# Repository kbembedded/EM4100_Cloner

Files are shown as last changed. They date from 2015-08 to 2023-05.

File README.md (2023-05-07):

EM4100 Cloner
=================

This RFID project is the second iteration of the RFID board for DEF CON's DarkNet game.  This project is based on the OPEN RFID tag with resources pulled from t4f.org and kukata86.com.  Envelope detector credit to multiple people listed here: http://playground.arduino.cc/Main/DIYRFIDReader

This project is to create a battery powered RFID cloner that is compatible with LF 125kHz RFID tags, a.k.a. EM4100.  There are 16 slots each able to store a 5 ID.  This device does not clone a tag and reprogram another, it is able to read and clone a tag and then turn around to emulate it to a proper transponder.  There is also a mechanism to manually program an ID to the device via the button and DIP switch.  Any of the 16 slots can have a cloned ID saved, a manually input ID saved, and an ID replayed from.

2023-05-06: I've discovered that Microchip has radically changed their assembler system. This will not compile under current MPLAB X IDEs, but should work on the older v3.50 or v3.55 (I think is what was originally used). They can still be found here: [https://www.microchip.com/en-us/tools-resources/archives/mplab-ecosystem#MPLAB%20XC%20Compiler%20Archives](https://www.microchip.com/en-us/tools-resources/archives/mplab-ecosystem#MPLAB%20XC%20Compiler%20Archives) If that link ever goes stale, well, good luck.

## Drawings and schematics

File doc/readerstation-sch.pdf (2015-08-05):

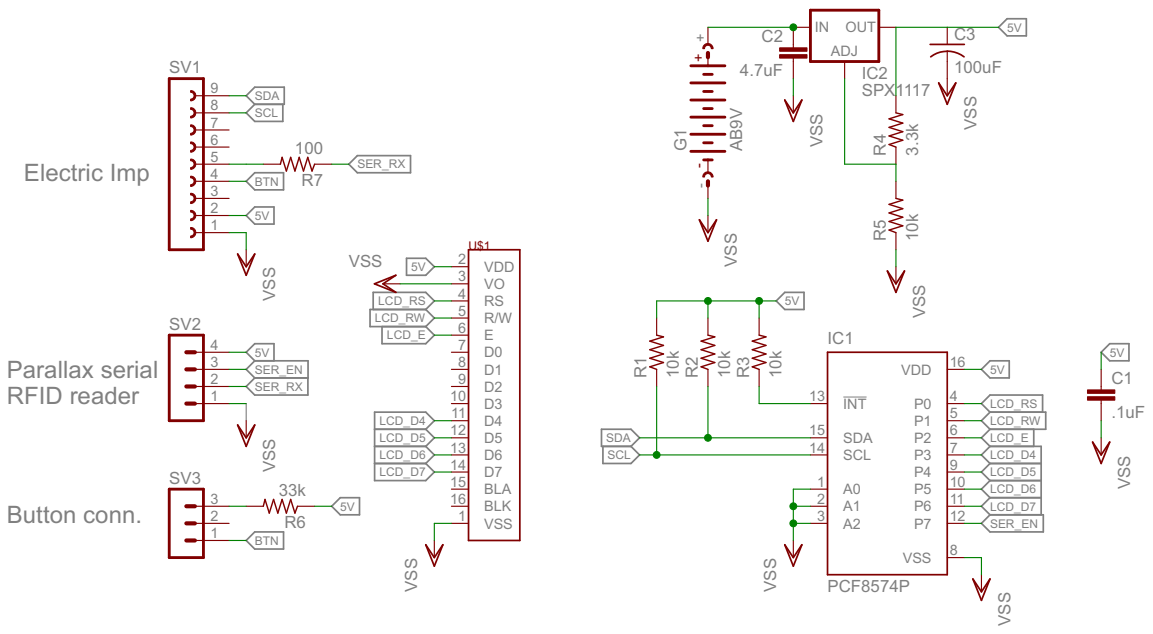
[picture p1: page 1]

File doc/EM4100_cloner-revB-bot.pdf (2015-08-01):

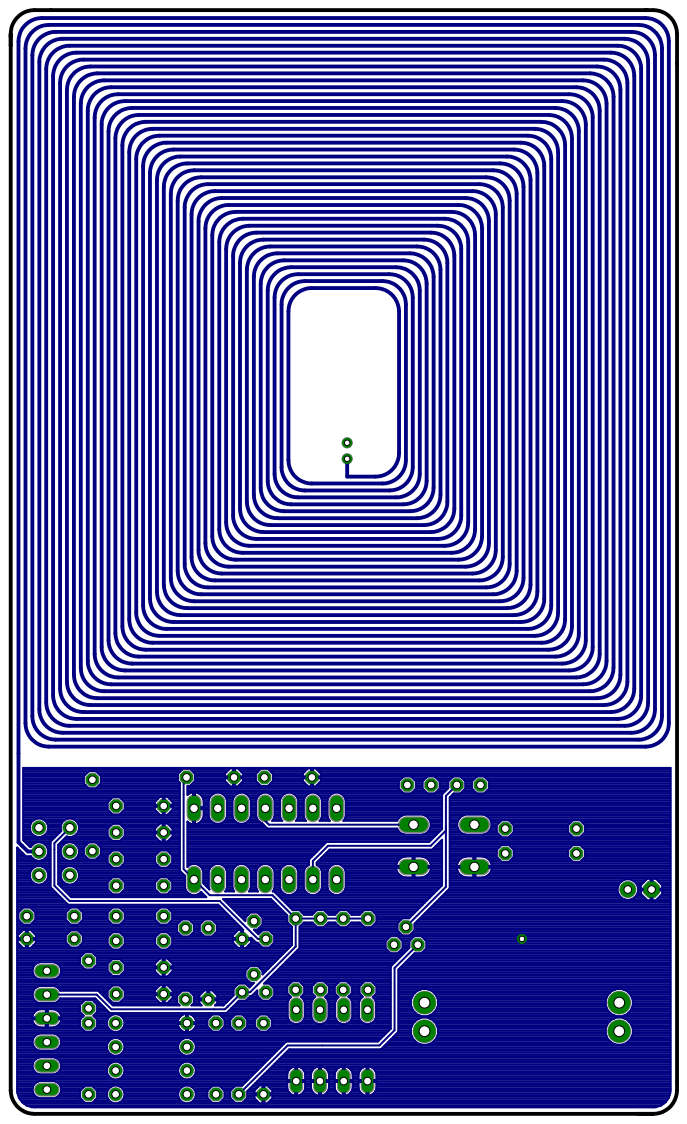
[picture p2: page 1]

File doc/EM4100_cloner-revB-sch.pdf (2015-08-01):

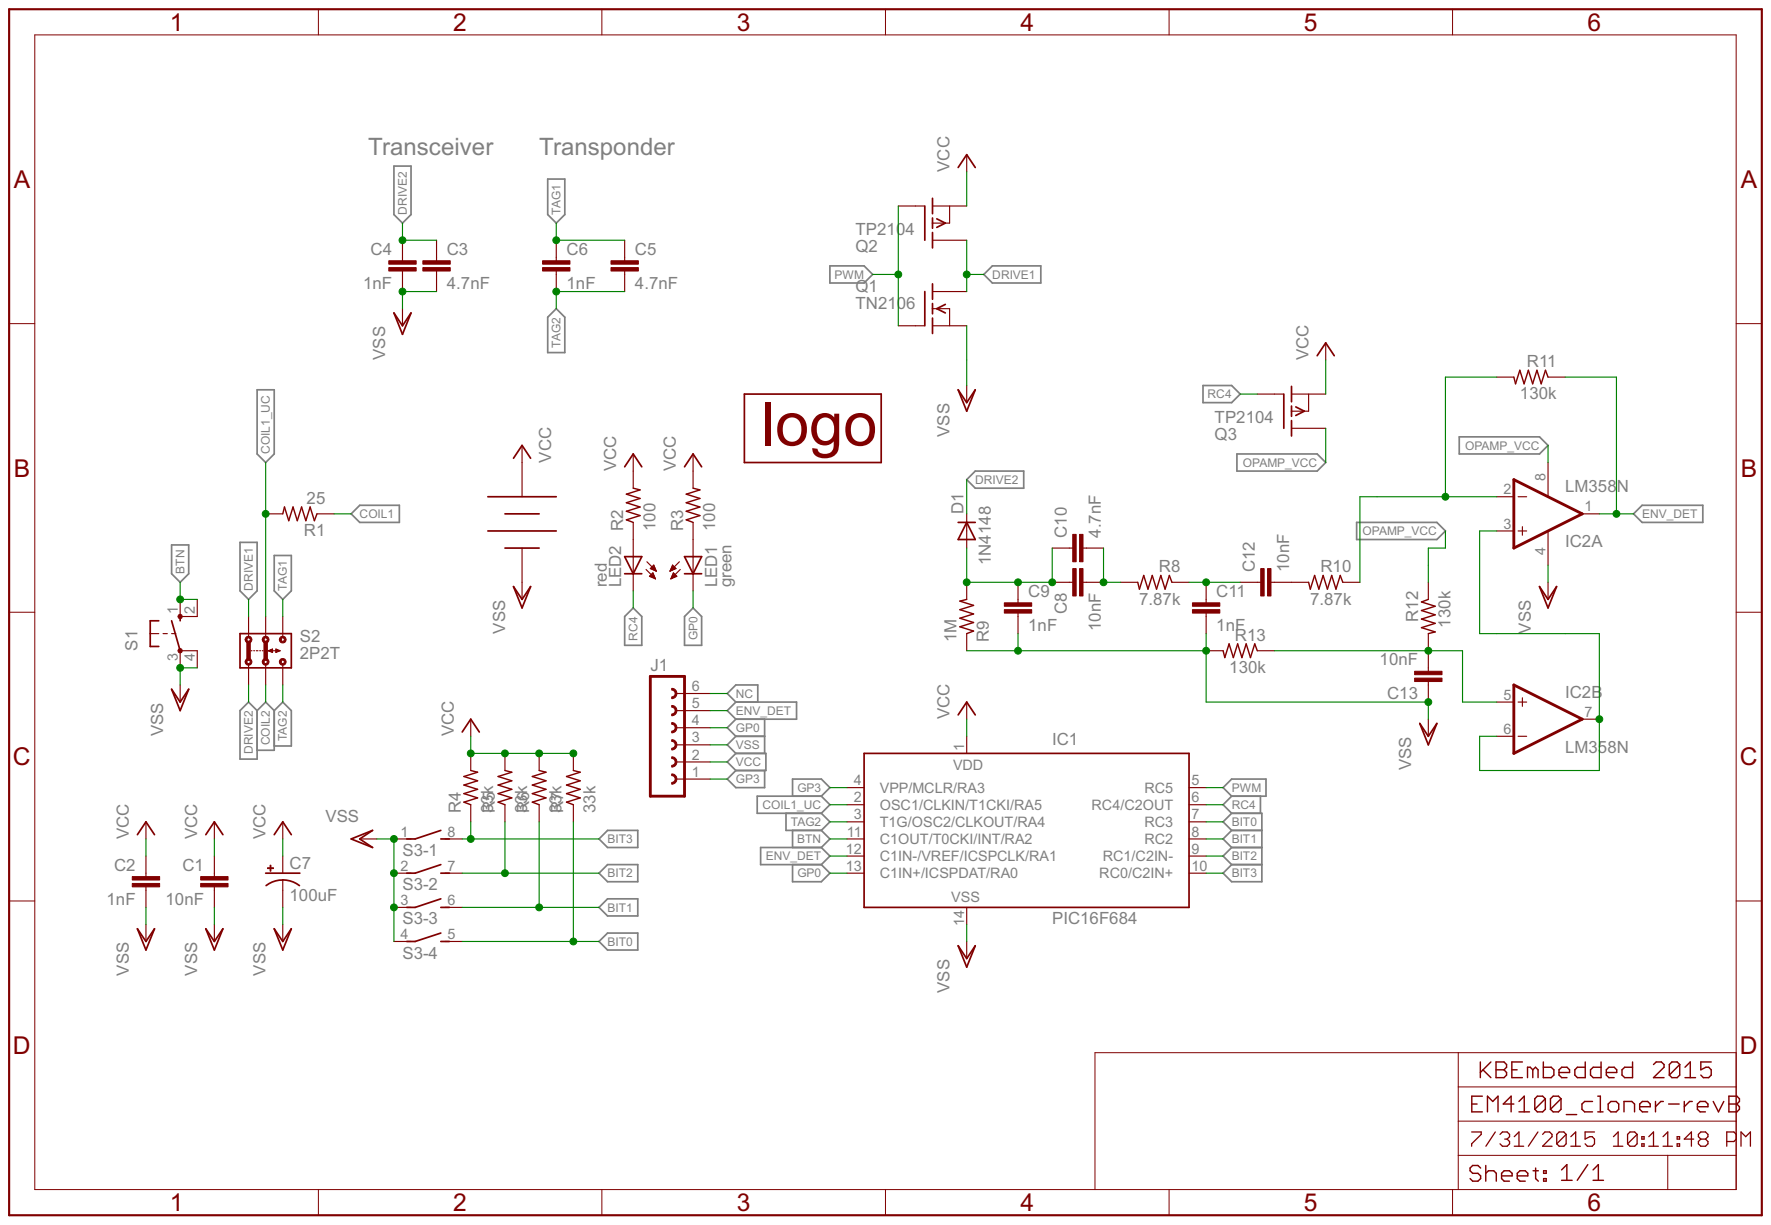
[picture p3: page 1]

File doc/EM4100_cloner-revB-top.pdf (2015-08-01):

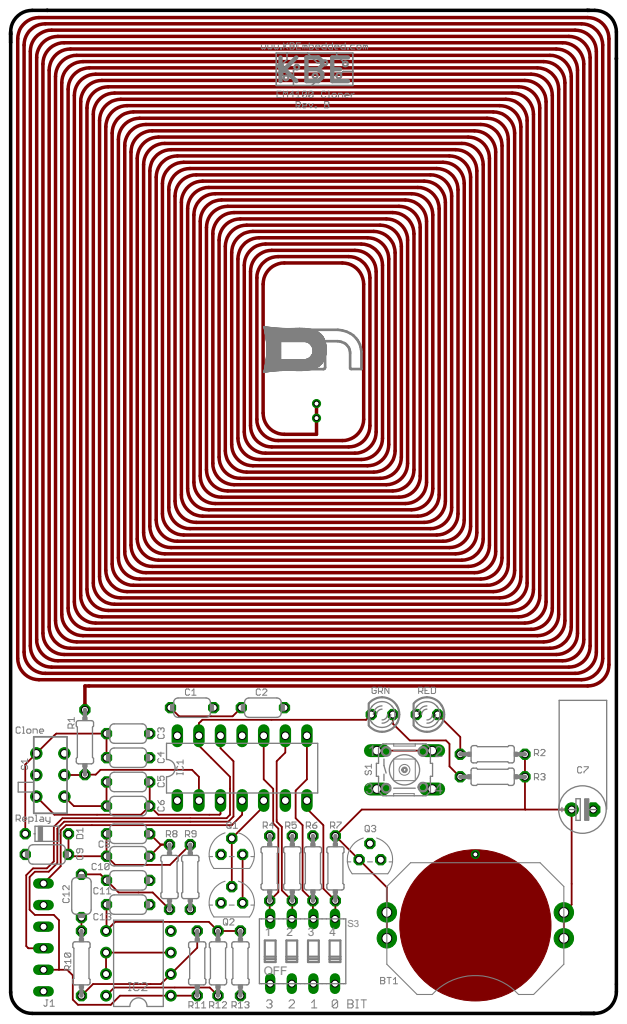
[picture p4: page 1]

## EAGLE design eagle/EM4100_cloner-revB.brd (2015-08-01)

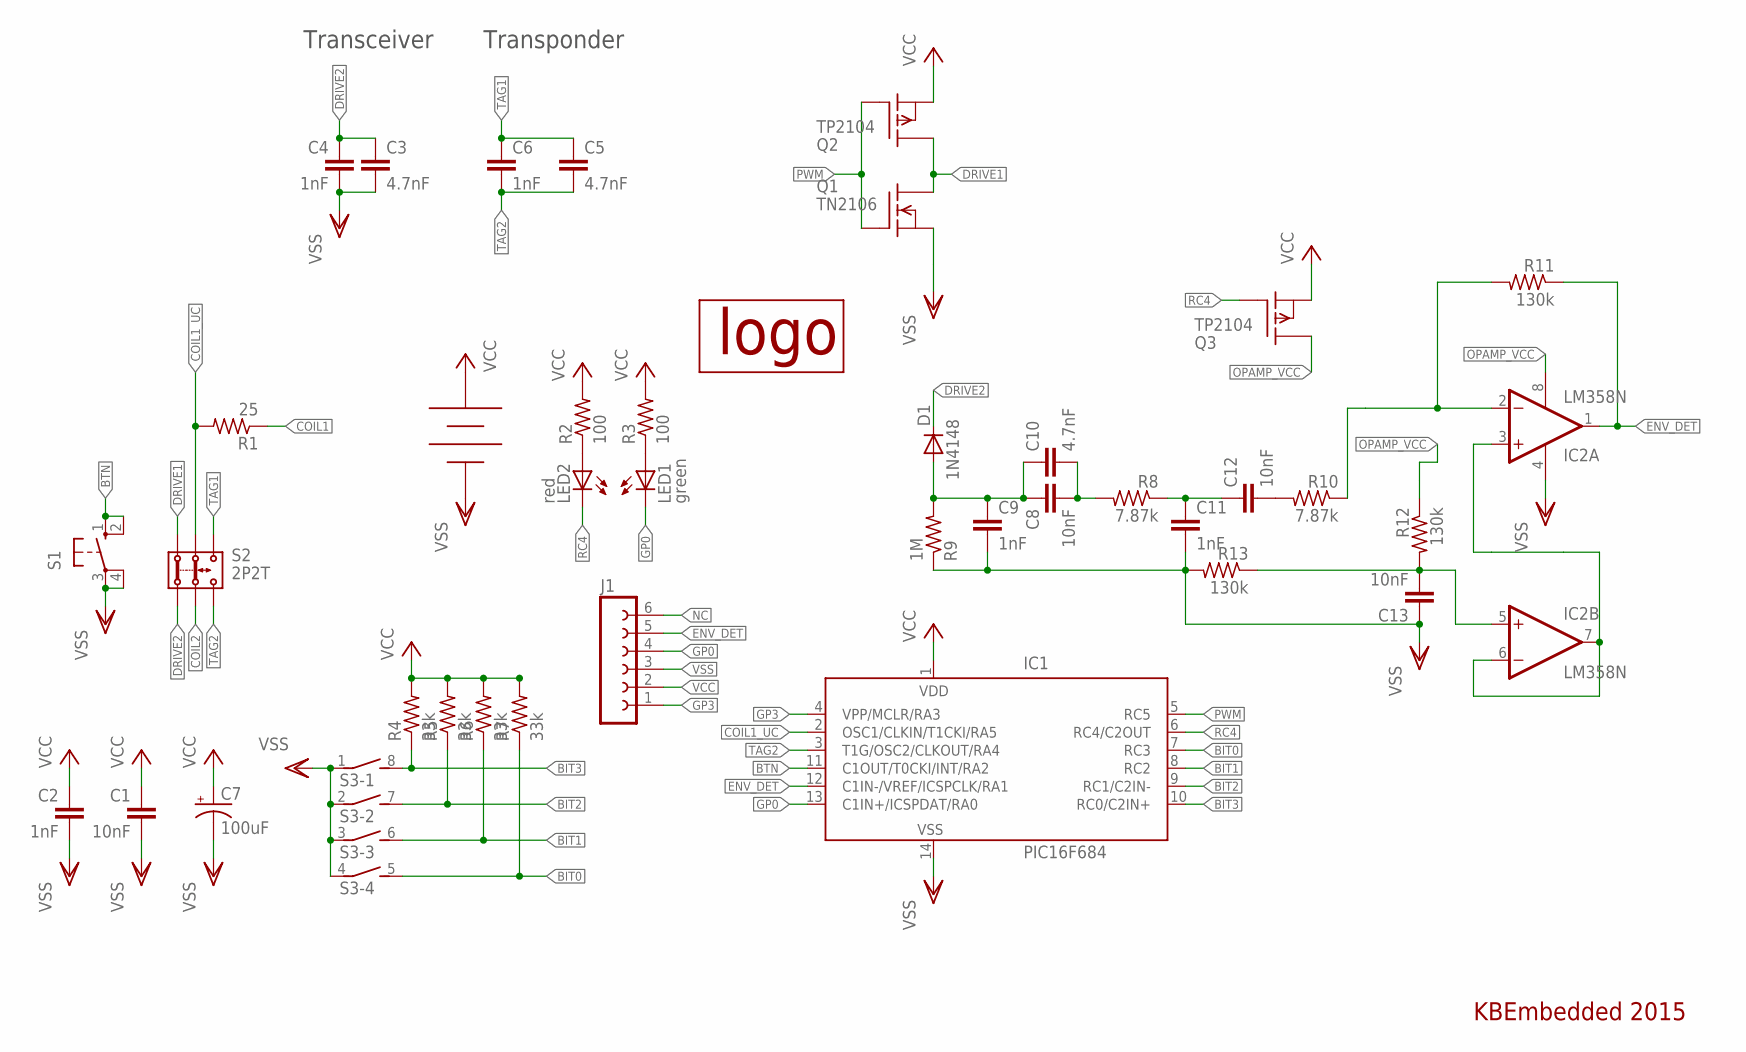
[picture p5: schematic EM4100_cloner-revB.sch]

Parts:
BT1: BAT-HLD-001-THM
C1, C8, C12, C13: 10nF; C050-024X044
C2, C4, C6, C9, C11: 1nF; C050-024X044
C3, C5, C10: 4.7nF; C050-024X044
C7: 100uF; E2,5-6E
D1: 1N4148; D-5
IC1: PIC16F684; DIL14
IC2: LM358N; DIL08
J1: FE06-1; FE06
LED1: green; LED3MM
LED2: red; LED3MM
Q1: TN2106; TO-92
Q2, Q3: TP2104; TO-92
R1: 25; 0204/7
R2, R3: 100; 0204/7
R4, R5, R6, R7: 33k; 0204/7
R8, R10: 7.87k; 0204/7
R9: 1M; 0204/7
R11, R12, R13: 130k; 0204/7
S1: 10-XX; B3F-10XX
S2: 2P2T
S3: DIP04S
U$1: KBELOGO-SILK

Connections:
BIT0: IC1.7 (RC3), R7.1, S3.5 (2)
BIT1: IC1.8 (RC2), R6.1, S3.6 (2)
BIT2: IC1.9 (RC1/C2IN-), R5.1, S3.7 (2)
BIT3: IC1.10 (RC0/C2IN+), R4.1, S3.8 (2)
BTN: IC1.11 (C1OUT/T0CKI/INT/RA2), S1.1 (S), S1.2 (S1)
COIL1: R1.1
COIL1_UC: IC1.2 (OSC1/CLKIN/T1CKI/RA5), R1.2, S2.2.1
COIL2: S2.2.2
DRIVE1: Q1.3 (D), Q2.3 (D), S2.1.1
DRIVE2: C3.1, C4.1, D1.C, S2.1.2
ENV_DET: IC1.12 (C1IN-/VREF/ICSPCLK/RA1), IC2.1 (OUT), J1.5, R11.1
GP0: IC1.13 (C1IN+/ICSPDAT/RA0), J1.4, LED1.K (C)
GP3: IC1.4 (VPP/MCLR/RA3), J1.1
unnamed: LED2.A, R2.1
unnamed: LED1.A, R3.1
unnamed: C8.1, C9.1, C10.1, D1.A, R9.2
unnamed: C8.2, C10.2, R8.2
unnamed: C11.1, C12.1, R8.1
unnamed: C12.2, R10.2
unnamed: IC2.3 (+IN), IC2.6 (-IN), IC2.7 (OUT)
unnamed: C13.2, IC2.5 (+IN), R12.2, R13.1
unnamed: IC2.2 (-IN), R10.1, R11.2
NC: J1.6
OPAMP_VCC: IC2.8 (V+), Q3.3 (D), R12.1
PWM: IC1.5 (RC5), Q1.2 (G), Q2.2 (G)
RC4: IC1.6 (RC4/C2OUT), LED2.K (C), Q3.2 (G)
TAG1: C5.1, C6.1, S2.3.1
TAG2: C5.2, C6.2, IC1.3 (T1G/OSC2/CLKOUT/RA4), S2.3.2
VCC: BT1.+@0 (VCC), BT1.+@1 (VCC), BT1.+@2 (VCC), BT1.+@3 (VCC), C1.1, C2.1, C7.+, IC1.1 (VDD), J1.2, Q2.1 (S), Q3.1 (S), R2.2, R3.2, R4.2, R5.2, R6.2, R7.2
VSS: BT1.- (VSS), C1.2, C2.2, C3.2, C4.2, C7.-, C9.2, C11.2, C13.1, IC1.14 (VSS), IC2.4 (V-), J1.3, Q1.1 (S), R9.1, R13.2, S1.3, S1.4 (P1), S3.1, S3.2 (1), S3.3 (1), S3.4 (1)

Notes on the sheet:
Transceiver
Transponder
KBEmbedded 2015

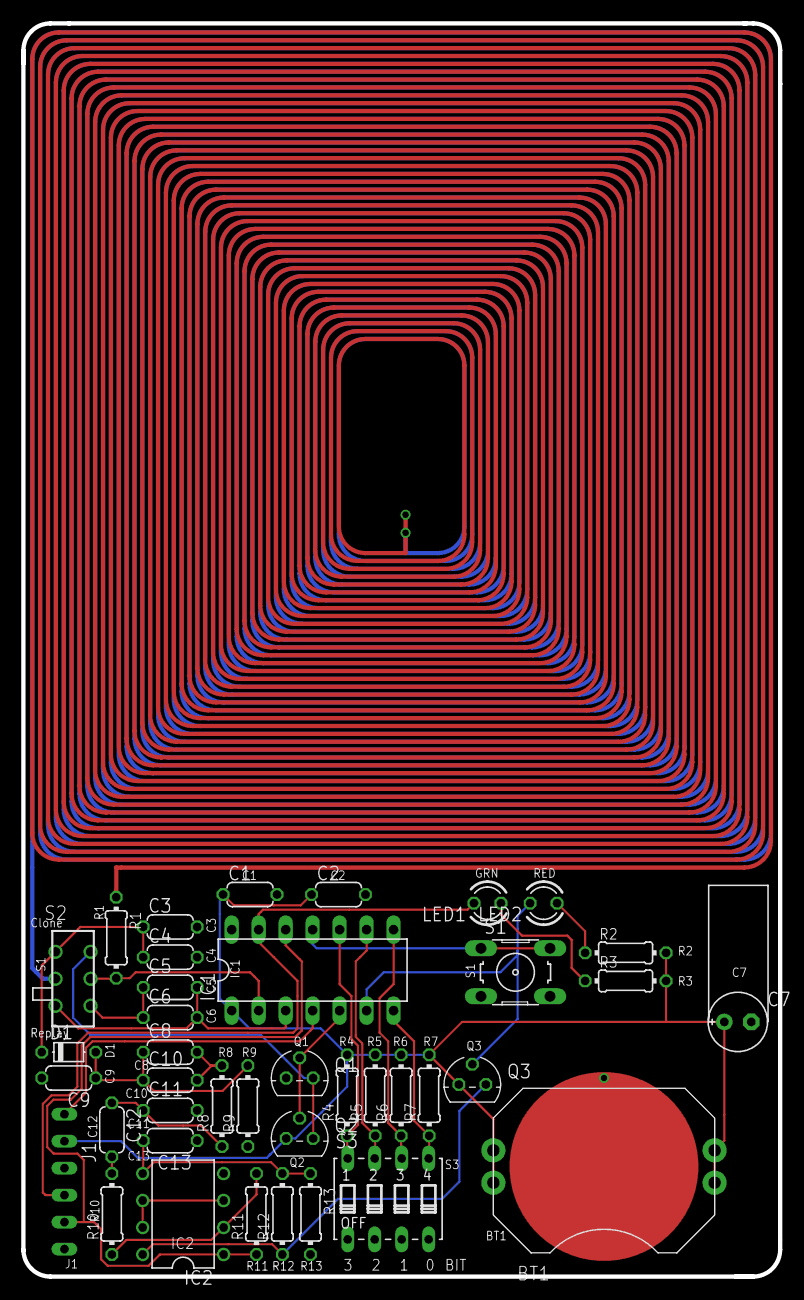
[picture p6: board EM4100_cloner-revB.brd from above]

Board: 2 copper layers, 71.2 x 118.0 mm, 41 parts (0 on the bottom side), 27 nets.

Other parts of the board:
U$2: DN_LOGO

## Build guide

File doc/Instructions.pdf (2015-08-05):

# EM4100 RFID Cloner Kit

This kit contains everything needed to build a low-frequency (125 kHz) EM4100 compatible device capable of cloning and replaying RFID tags. All of the documentation, hardware, and software is available on github: https://github.com/kbembedded/EM4100_Cloner
The whole device is controlled by a PIC16F684 microcontroller, which is pre-programmed. The software currently supports cloning of read-only LF RFID tags, a manual input of arbitrary IDs, and replaying the stored IDs to standard RFID transceivers. There are a total of 16 locations available to save IDs to or replay from.
If you have any issues, are missing parts, or just have questions, ask in the Hardware Hacking Village at DEF CON, or send an email to support@kbembedded.com

See the schematic and layout PDFs, located in the doc/
directory for more information about the circuit
Label | Description | Notes about assembly:
R1 | 25 Ohm | IC1, IC2, S2, S3, C7, D1, GRN, RED, BT1 and Q1-Q3
R2, R3 | 100 Ohm | IC1 and IC2 have notches on the chip and the PCB that should match up
R4, R5, R6, R7 | 33 kOhm | S2 has the slider tab marked on the PCB to note orientation.
R8, R10 | 7.87 kOhm | S3 has a white dot on the upper-right corner and lines up with “S3”
R9 | 1M Ohm | C7 has a white stripe on the negative (cathode) side of the capacitor. The
R11, R12, R13 | 130 kOhm | capacitor must be mounted with the stripe opposite the “+” symbol.
IC1 | PIC16F684 | D1 must have the stripe on the component match the stripe on the PCB
IC2 | LM258/LM358 | GRN & RED both have one leg shorter than the other; the shorter leg is the
S2 | Slide Switch (mislabeled on PCB) | negative (cathode) leg and needs to line up with the flat side printed on
D1 | 1N4148 Signal Diode | the PCB.
C2, C4, C6, C9, C11 | 1 nF Ceramic | BT1 must be mounted with the concave circle closest to the edge of the
C3, C5, C10 | 4.7 nF Ceramic | PCB.
C1, C8, C12, C13 | 10 nF Ceramic | Q1-Q3 must be mounted facing the same was as the silkscreen on the PCB
C7 | 100 uF Aluminum, lay flat | J1 is optional and can be used to reprogram the PIC
BT1 | CR2032 Battery Holder
S1 | Push Switch | The backside of the PCB has 16 blocks of silkscreen that can be used to make
S3 | DIP Switch | notes about what IDs are saved in each of the save locations. Wet-erase and
Q1 | N-Chan. MOSFET (2106) | permanent markers work well in these blocks.
Q2, Q3 | P-Chan. MOSFET (2104)
GRN | Green LED | For S3, switch down is a binary 0, and switch up is a binary 1
RED | Red LED
J1 | 6-pin RA header (optional)
Operation instructions:
The EM4100 cloner kit has three modes of operation: clone, replay, and manual input. The DIP switch is used as a way to select the location to save to, or read from. While the DIP switch has numbers on it, the numbers listed next to the “BIT” designator under the DIP switch are used to represent the bit values, i.e. leftmost switch is bit 3, and rightmost switch is bit 0.
Clone an RFID tag:
Slide S2 in to the “Clone” position and set the save location on the DIP switch. Warning! If an ID is successfully cloned, it will be written to this save location and will destroy the ID that was saved there previously! Hold down the button S1 and the red LED will light up. Bring the device near a 125 kHz RFID tag and when the tag is successfully read and saved, the red LED will turn off and the green one will turn on. You can now release the button and the cloner will go back to sleep.
Replay an RFID tag:
Slide S2 in to the “Replay” position and set the location on the DIP switch. This will replay the ID stored at the selected location. This mode is passive and the microcontroller will only wake up when another transceiver sends a 125 kHz carrier signal. Once a valid carrier signal is detected, the cloner will synchronize to it and continuously replay the ID in the selected location. Note that the PIC (and LF RFID in general) is extremely low power, and a device may still be able to be read while in “Replay” mode even with the battery removed.
Manually input a tag ID:
Slide S2 in to the “Replay” position and set the save location on the DIP switch. Warning! If an ID is successfully entered, it will be written to this save location and will destroy the ID that was saved there previously! Press and hold down the button S1 for 5 seconds and both LEDs will turn on. Release the switch and the green LED will turn off. The new ID to be saved is now input using the DIP switch, one nibble at a time, starting with the most significant nibble of the ID and moving right. Input the nibble to the DIP switch, press and release S1, and the LED will toggle from red to green when depressed, and back to red when released. This process is repeated 9 times for all 10 nibbles. If at any time while in this mode S1 is not depressed for 20 seconds, the cloner will go back to sleep and no changes will be made to the selected ID location.
For example, to input an ID of ABCDEF0123 to location 4:
Slide S2 to “Replay”, set 4 on the DIP switch (0100), hold the button for 5 seconds until the LEDs turn on then release the button.
Set 0xA (1010) on the DIP switch, depress and release the button S1.
Set 0xB (1011) on the DIP switch, depress and release the button S1.
Set 0xC (1100) on the DIP switch, depress and release the button S1.
Repeat for all 10 nibbles of the ID
No touchy zone:
The analog signal detector circuit is capacitively sensitive and the additional capacitance that the body has will affect performance of the circuit if touched. The back of the PCB has a section that is outlined called the “No touchy zone.” Be sure to not come in to contact with this section of the PCB on the back while operating the cloner as it will have an adverse affect.

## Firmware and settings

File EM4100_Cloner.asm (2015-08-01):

;The MIT License (MIT)
;
;Copyright (c) 2014 KBEmbedded
;
;This project is based on the OPEN RFID tag with resources pulled from t4f.org
;and kukata86.com.
;
;Permission is hereby granted, free of charge, to any person obtaining a copy of
;this software and associated documentation files (the "Software"), to deal in
;the Software without restriction, including without limitation the rights to
;use, copy, modify, merge, publish, distribute, sublicense, and/or sell copies of
;the Software, and to permit persons to whom the Software is furnished to do so,
;subject to the following conditions:
;
;The above copyright notice and this permission notice shall be included in all
;copies or substantial portions of the Software.
;
;THE SOFTWARE IS PROVIDED "AS IS", WITHOUT WARRANTY OF ANY KIND, EXPRESS OR
;IMPLIED, INCLUDING BUT NOT LIMITED TO THE WARRANTIES OF MERCHANTABILITY, FITNESS
;FOR A PARTICULAR PURPOSE AND NONINFRINGEMENT. IN NO EVENT SHALL THE AUTHORS OR
;COPYRIGHT HOLDERS BE LIABLE FOR ANY CLAIM, DAMAGES OR OTHER LIABILITY, WHETHER
;IN AN ACTION OF CONTRACT, TORT OR OTHERWISE, ARISING FROM, OUT OF OR IN
;CONNECTION WITH THE SOFTWARE OR THE USE OR OTHER DEALINGS IN THE SOFTWARE.

#include "EM4100_Cloner.inc"
#include "../Common/EM4100_Cloner_io.inc"
#include "../Common/EM4100_Cloner_misc.inc"
#include "../Common/EM4100_Cloner_rf.inc"

__CONFIG _CPD_OFF & _WDT_OFF & _BOD_OFF & _PWRTE_ON & _INTRC_OSC_NOCLKOUT & _MCLRE_ON & _IESO_OFF & _FCMEN_OFF

EXTERN  _initIO
EXTERN  _pauseWx10us, _pauseWx1ms
EXTERN  _initRF_common
EXTERN  _writeEEPROM, PARAM1
EXTERN  _start_PLAY
EXTERN  _read_DIP
EXTERN  _manual_input

;;;;;;;;;;;;;;;;;;;;;;;;;;;;;;;;;;;;;;;;;;;;;;;;;;;;;;;;;;;;;;;;;;;;;;;;;;;;;;;;
;;;                                                                          ;;;
;;                                GLOBALS                                     ;;
;;;                                                                          ;;;
;;;;;;;;;;;;;;;;;;;;;;;;;;;;;;;;;;;;;;;;;;;;;;;;;;;;;;;;;;;;;;;;;;;;;;;;;;;;;;;;

GLOBAL  EE_MEMORY_SIZE, EE_CLOCKS_PER_BIT, EE_TAG_MODE, EE_RFID_MEMORY
GLOBAL  FLAGS, PARITY, COLUMN_PARITY, NIBBLE_CNT
GLOBAL  LATA, LATC, DIP_NIBBLE, _WDT_reset, RFID_MEMORY, write_RFID

;;;;;;;;;;;;;;;;;;;;;;;;;;;;;;;;;;;;;;;;;;;;;;;;;;;;;;;;;;;;;;;;;;;;;;;;;;;;;;;;
;;;                                                                          ;;;
;;                                LITERALS                                    ;;
;;;                                                                          ;;;
;;;;;;;;;;;;;;;;;;;;;;;;;;;;;;;;;;;;;;;;;;;;;;;;;;;;;;;;;;;;;;;;;;;;;;;;;;;;;;;;

#DEFINE RECORD             0 ; Flag: Are we writing to RFID Memory?
#DEFINE ERR                1 ; Flag: Error with manchester decoding
#DEFINE NUM_BIT_MANCHESTER 2 ; Flag: Which manchester bit are we on?
#DEFINE MANUAL             3 ; Flag: Manual input mode
#DEFINE BIT                5 ; Flag: Does this bit need to be demodulated?
#DEFINE WAS_T              6 ; Flag: Last bit was T and next bit needs to be checked
#DEFINE CAPTURE            7 ; Flag: If set, we are CAPTURING a tag

;;;;;;;;;;;;;;;;;;;;;;;;;;;;;;;;;;;;;;;;;;;;;;;;;;;;;;;;;;;;;;;;;;;;;;;;;;;;;;;;
;;;                                                                          ;;;
;;                                VARIABLES                                   ;;
;;;                                                                          ;;;
;;;;;;;;;;;;;;;;;;;;;;;;;;;;;;;;;;;;;;;;;;;;;;;;;;;;;;;;;;;;;;;;;;;;;;;;;;;;;;;;

    UDATA
RFID_MEMORY             RES .11

    UDATA_SHR
LATA                    RES .1  ; Shadow registers for PORTs
LATC                    RES .1
FLAGS                   RES .1  ; Flags defined above.

TMP                     RES .1
W_TEMP                  RES .1
STATUS_TEMP             RES .1

EEPROM_ADDRESS          RES .1

MANCHESTER_BIT_IDX      RES .1  ; Manchester bit index
PACKET                  RES .1

NIBBLE_CNT              RES .1  ; Number of Nibbles remaining to receive
DIP_NIBBLE              RES .1
PARITY                  RES .1
COLUMN_PARITY           RES .1
CONFIG_CLOCKS_PER_BIT   RES .1

TRASH   UDATA   0xA0

TRASH                   RES .32 ; WARNING! We reserve all the GPRs in the BANK1
                                ; to avoid the linker using them.
                                ; This way, we force the linker to alloc all
                                ; the vars in the BANK0.
                                ;
                                ; The "good" way to do this is doing a linker
                                ; script.

;;;;;;;;;;;;;;;;;;;;;;;;;;;;;;;;;;;;;;;;;;;;;;;;;;;;;;;;;;;;;;;;;;;;;;;;;;;;;;;;
;;;                                                                          ;;;
;;                                  CODE                                      ;;
;;;                                                                          ;;;
;;;;;;;;;;;;;;;;;;;;;;;;;;;;;;;;;;;;;;;;;;;;;;;;;;;;;;;;;;;;;;;;;;;;;;;;;;;;;;;;


RST_VECTOR      CODE    0x0000

    GOTO      _start


INT_VECTOR      CODE    0x0004

    ; XXX: See note about PCLATH on pg 109 of datasheet with interrupts on gotos
    ; Save the actual context
    MOVWF   W_TEMP
    SWAPF   STATUS,W
    BCF     STATUS,RP0
    MOVWF   STATUS_TEMP

    BTFSC   INTCON, RAIF
    CALL    _ISR_gpio

    BTFSC   INTCON, T0IF
    CALL    _ISR_timer

_ISR_exit
    ; Restore the context
    SWAPF   STATUS_TEMP,W
    MOVWF   STATUS
    SWAPF   W_TEMP,F
    SWAPF   W_TEMP,W

    RETFIE

_ISR_gpio
    ; If we end up here, we have a GPIO interrupt
    ; If button is released, and we're not in capture mode, the interrupt was from the coil
    ; If button is pressed, and we're not in capture mode, test coil for connection, enter capture mode
    ; If button is released, and we're in capture mode, reset
    ; If button is pressed, and we're in capture mode, reset

    BTFSC   FLAGS, CAPTURE
    GOTO    _WDT_reset

    MOVLW   .20
    CALL    _pauseWx1ms             ; Debounce

    BTFSC   BTN
    GOTO    _ISR_gpio_exit

    ; At this point, test for connection across coil
    BANKSEL TRISC
    BCF     COIL1_TRIS
    BANKSEL PORTA

    BCF     COIL1
    MOVF    LATA, W
    MOVWF   PORTA
    MOVLW   .1
    CALL    _pauseWx1ms

    BTFSS   PORTA, RA5                   ; Coil conn. means tag switch pos.
    BSF     FLAGS, MANUAL

    BSF     FLAGS, CAPTURE
    
    BANKSEL TRISC
    BSF     COIL1_TRIS
    BANKSEL PORTA

    

_ISR_gpio_exit
    BANKSEL IOCA
    BCF     IOCA, IOC5              ; We don't want to get another IRQ from GP5
    BANKSEL PORTA
    MOVF    PORTA, W                ; Read PORTA to clear interrupt condition
    BCF     INTCON, RAIF
    RETURN

_ISR_timer
    BTFSS   INTCON, T0IE            ; Verify the interrupt is actually enabled.
    RETURN

    GOTO    _WDT_reset
    RETURN

_WDT_reset
    CLRF    WDTCON
    BSF     WDTCON, SWDTEN
    GOTO    $
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

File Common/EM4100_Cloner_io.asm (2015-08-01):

;The MIT License (MIT)
;
;Copyright (c) 2014 KBEmbedded
;
;This project is based on the OPEN RFID tag with resources pulled from t4f.org
;and kukata86.com.
;
;Permission is hereby granted, free of charge, to any person obtaining a copy of
;this software and associated documentation files (the "Software"), to deal in
;the Software without restriction, including without limitation the rights to
;use, copy, modify, merge, publish, distribute, sublicense, and/or sell copies of
;the Software, and to permit persons to whom the Software is furnished to do so,
;subject to the following conditions:
;
;The above copyright notice and this permission notice shall be included in all
;copies or substantial portions of the Software.
;
;THE SOFTWARE IS PROVIDED "AS IS", WITHOUT WARRANTY OF ANY KIND, EXPRESS OR
;IMPLIED, INCLUDING BUT NOT LIMITED TO THE WARRANTIES OF MERCHANTABILITY, FITNESS
;FOR A PARTICULAR PURPOSE AND NONINFRINGEMENT. IN NO EVENT SHALL THE AUTHORS OR
;COPYRIGHT HOLDERS BE LIABLE FOR ANY CLAIM, DAMAGES OR OTHER LIABILITY, WHETHER
;IN AN ACTION OF CONTRACT, TORT OR OTHERWISE, ARISING FROM, OUT OF OR IN
;CONNECTION WITH THE SOFTWARE OR THE USE OR OTHER DEALINGS IN THE SOFTWARE.


	#include "EM4100_Cloner_io.inc"
    #include "EM4100_Cloner_rf.inc"

    GLOBAL	_initIO, _read_DIP, _manual_input
    EXTERN  LATA, LATC, DIP_NIBBLE, RFID_MEMORY, PARITY, COLUMN_PARITY, NIBBLE_CNT
    EXTERN  _WDT_reset, _pauseWx10us, _pauseWx1ms, write_RFID




;;;;;;;;;;;;;;;;;;;;;;;;;;;;;;;;;;;;;;;;;;;;;;;;;;;;;;;;;;;;;;;;;;;;;;;;;;;;;;;;
;;;                                                                          ;;;
;;                                VARIABLES                                   ;;
;;;                                                                          ;;;
;;;;;;;;;;;;;;;;;;;;;;;;;;;;;;;;;;;;;;;;;;;;;;;;;;;;;;;;;;;;;;;;;;;;;;;;;;;;;;;;
    UDATA
TMP     RES .1
DIP_TMP RES .1
ADDRESS RES .1
	
	

;;;;;;;;;;;;;;;;;;;;;;;;;;;;;;;;;;;;;;;;;;;;;;;;;;;;;;;;;;;;;;;;;;;;;;;;;;;;;;;;
;;;                                                                          ;;;
;;                                  CODE                                      ;;
;;;                                                                          ;;;
;;;;;;;;;;;;;;;;;;;;;;;;;;;;;;;;;;;;;;;;;;;;;;;;;;;;;;;;;;;;;;;;;;;;;;;;;;;;;;;;

	CODE



;;;;;;;;;;;;;;;;;;;;;;;;;;;;;;;;;;;;;;;;;;;;;;;;;;;;;;;;;;;;;;;;;;;;;;;;;;;;;;;;
;;;                                                                          ;;;
;;                                                                            ;;
;    Function:  _initIO                                                        ;
;    Desc.:     Initialize the Input/Output devices (LEDS & BUTTONS)          ;
;    Params.:   NONE                                                           ;
;                                                                              ;
;    Notes:     Returns in Bank 0                                              ; 
;;                                                                            ;;
;;;                                                                          ;;;
;;;;;;;;;;;;;;;;;;;;;;;;;;;;;;;;;;;;;;;;;;;;;;;;;;;;;;;;;;;;;;;;;;;;;;;;;;;;;;;;

_initIO
    ; XXX: Can the LED enable code be cleaned up at all?
    BANKSEL TRISA

    CLRF    ANSEL 					; GPIO as digital IOs

    BCF     OPTION_REG, NOT_RAPU	; PULL-UPs activated on GPIO
    
    BSF     IOCA, IOC5              ; Enable interrupt on change for coil
    BSF     IOCA, IOC2

    ; Manual conflicts itself with PORTx value on WDT reset, lets just be safe
    BANKSEL PORTA
    CLRF    PORTA                   ; Init PORT to known values
    CLRF    PORTC
    CLRF    LATA
    CLRF    LATC
    LED1_OFF
    LED2_OFF

    BANKSEL TRISA
    BCF     LED1_TRIS				; LEDs as output
    BCF     LED2_TRIS
    BCF     TRISC, RC5              ; Set PWM as low output, prevent floppy FETs
    BCF     DEMODULATOR_TRIS        ; Set Demodulator as low output

    BANKSEL PORTA
    MOVLW    07h 					; Disable the analog comparators
    MOVWF    CMCON0

    MOVLW   .50                     ; Wait for debouncing
    CALL    _pauseWx10us

    BSF     INTCON, RAIE            ; Enable interrupt for RA
	
    RETURN

_read_DIP
    MOVF    PORTC, W
    MOVWF   DIP_TMP
    COMF    DIP_TMP, F

    ; Roll bit positions due to layout from 0123 to 3210
    RRF     DIP_TMP, F
    RLF     DIP_NIBBLE, F
    RRF     DIP_TMP, F
    RLF     DIP_NIBBLE, F
    RRF     DIP_TMP, F
    RLF     DIP_NIBBLE, F
    RRF     DIP_TMP, F
    RLF     DIP_NIBBLE, F

    MOVLW   b'00001111'
    ANDWF   DIP_NIBBLE, F
    RETURN

_manual_input
    MOVF    DIP_NIBBLE, W
    MOVWF   ADDRESS
    ; XXX: This is pretty ugly and thrown together for functionality ASAP
    ;        Will have to clean this up later
    BCF     INTCON, GIE
    ; From this point, we're not using an interrupt

    MOVLW   .40
    MOVWF   TMP

_manual_enter
    ; Make sure the button is held for 4 seconds
    MOVLW   .100
    CALL    _pauseWx1ms

    BTFSC   BTN
    GOTO    _WDT_reset

    DECFSZ  TMP
    GOTO    _manual_enter

    LED1_ON
    LED2_ON

    BTFSS   BTN
    GOTO    $-1

    LED2_OFF

    MOVLW   RFID_MEMORY             ; Load INDF with start of RFID_MEMORY
    MOVWF   FSR

    CLRF    COLUMN_PARITY
    MOVLW   .10
    MOVWF   NIBBLE_CNT              ; TODO: Pull this from EEPROM?

_manual_timer
    MOVLW   .200
    MOVWF   TMP
_manual_loop

    MOVLW   .100
    CALL    _pauseWx1ms

    BTFSC   BTN
    GOTO    _end_manual_loop

    CALL    _read_DIP
    CLRF    PARITY

    LED2_ON
    LED1_OFF

    BTFSS   BTN                     ; Wait for button to be released
    GOTO    $-1

    LED2_OFF
    LED1_ON

    MOVF    DIP_NIBBLE, W
    MOVWF   DIP_TMP

    RRF     DIP_TMP, F
    BTFSC   STATUS, C
    INCF    PARITY, F

    RRF     DIP_TMP, F
    BTFSC   STATUS, C
    INCF    PARITY, F

    RRF     DIP_TMP, F
    BTFSC   STATUS, C
    INCF    PARITY, F

    RRF     DIP_TMP, F
    BTFSC   STATUS, C
    INCF    PARITY, F

    BCF     STATUS, C
    RLF     DIP_NIBBLE, F

    ; DIP_NIBBLE is still in W
    XORWF   COLUMN_PARITY, F

    BTFSC   PARITY, 0
    INCF    DIP_NIBBLE, F                   ; Add one to parity if needed

    MOVF    DIP_NIBBLE, W
    MOVWF   INDF                            ; Copy the full nibble to RAM
    INCF    FSR, F

    DECFSZ  NIBBLE_CNT
    GOTO    _manual_timer

    BCF     STATUS, C
    RLF     COLUMN_PARITY, W
    MOVWF   INDF                            ; Save column parity

    MOVF    ADDRESS, W
    MOVWF   DIP_NIBBLE                      ; Restore the address we're saving to

    CALL    write_RFID
    ; We should never end up back here

    GOTO    _WDT_reset

_end_manual_loop
    DECFSZ  TMP
    GOTO    _manual_loop

    GOTO    _WDT_reset



    END
